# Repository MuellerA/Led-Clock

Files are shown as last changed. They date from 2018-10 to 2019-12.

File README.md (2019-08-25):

<h1>LED Clock</h1>

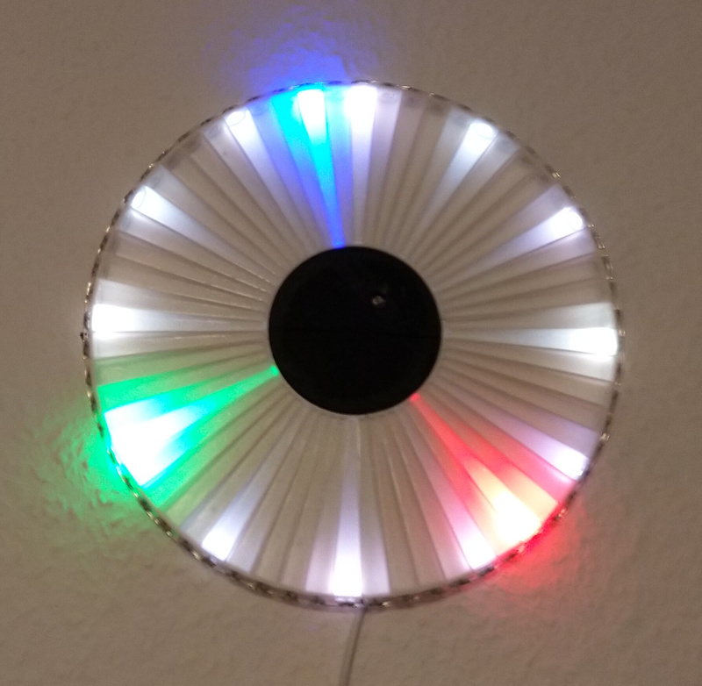
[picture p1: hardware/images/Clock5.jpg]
Clock


<p>Clock with WS2812 LEDs, controlled by a NodeMCU ESP8266 module.</p>
<p><span style="color: red">DO NOT EXPOSE THE CLOCK TO THE INTERNET<br/>The clock stores your WiFi credentials and supports remote updates</span></p>

<h2>Features</h2>
<ul>
  <li>Setting color for hour, minute, second</li>
  <li>Brighness control</li>
  <li>Use NTP for time synchronization</li>
  <li>Convert from UTC to local time and DST</li>
  <li>Manual and automatic time triggered On/Off</li>
  <li>OTA Update</li>
  <li>Optional secure HTTPS communication</li>
</ul>

<h2>Used Libraries</h2>
<ul>
  <li>Arduino 1.8.0</li>
  <li><a href="https://github.com/esp8266/Arduino">Arduino Core for ESP8266</a> (Version 2.4.2 - I had OTA Update problems with 2.5.0)</li>
  <li><a href="https://github.com/adafruit/Adafruit_NeoPixel">Adafruit NeoPixel Library</a> (Version 1.2.1)</li>
</ul>

<h2>Material</h2>
<ul>
  <li>NodeMCU v2</li>
  <li>Buck converter 12V to 5V</li>
  <li>60x WS2812 LEDs on PCB</li>
  <li>Photo resistor 5539</li>
  <li>3D printed housing</li>
  <li>Acryl glass front plate</li>
</ul>

<h2>Setup</h2>
<ol>
  <li>Open the Arduino IDE</li>
  <li>Install the required libraries</li>
  <li>Check the <a href="source/ArduinoSettings.png">Board Settings</a></li>
  <li>Load the Clock.ino sketch</li>
  <li>Modify the Password in password.h (it is used as PSK in Access Point mode and OTA Update password)</li>
  <li>Flash the ESP8266 using Arduino IDE</li>
  <li>
    Connect the NodeMCU with the buck converter, WS2812 LEDs and the photo resistor:<br/>
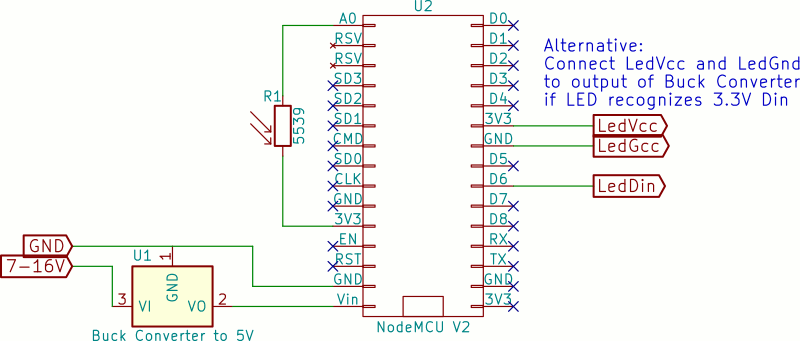
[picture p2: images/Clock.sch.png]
schematic
    <br/>
  </li>
</ol>

<h2>First Start</h2>
<ul>
  <li>Open the Serial Monitor in Arduino IDE</li>
  <li>Power on / reset the Clock</li>
  <li>Connect to Network with the SSID "Clock-xxxxxx" and the password specified in the password.h file (both are shown in the Serial Monitor)</li>
  <li>Open the web page "http://192.168.4.1"</li>
  <li>On the Settings page enter the credentials (SSID and PSK) of your Wireless LAN and press "save"</li>
  <li>The clock will now connect to your network, fetch the current time and display it</li>
  <li>Check your router for the network address of the Clock and open the page in the browser to check the other settings</li>
  <li>At next power on the clock will remember the settings</li>
</ul>

<h2>Usage</h2>
<ul>
  <li>The LEDs can be switched on/off manually and automatically. If automatic mode is enabled and the LEDs are switched manually, the automatic mode stays enabled and will switch at the next configured time again.</li>
  <li>The OTA Update username is the Name specified on the Settings page and the password is the one specified in password.h file</li>
</ul>

<h2>Security</h2>
<p>By default the Clock does not use https for communication, it's too slow. Https can be enabled in Clock.ino (#define HTTPS ...).</p>
<p>The repository contains a certificate and private key, but you should use your own. To create and upload them:</p>
<ol>
  <li>Run the script "source/make-cert.sh" to create the certificate file "cert.der" and the private key file "key.der". The script requires <a href="https://www.openssl.org/">OpenSSL</a> to be installed.</li>
  <li>Create the directory "source/Clock/data" and copy the generated files into that directory.</li>
  <li>Install the SPIFS tool for Arduino as described in the <a href="https://arduino-esp8266.readthedocs.io/en/latest/filesystem.html#uploading-files-to-file-system">ESP8266 documentation</a>.</li>
  <li>Use the Upload Tool to upload the files to the ESP8266.</li> 
</ol>

<h2>3D Print</h2>

<p>The OpenSCAD file to 3D Print the housing is in the hardware folder. STL files are available at <a href="https://www.thingiverse.com/thing:3130435">Thingiverse</a><br/>
An alternative to 3D Printing is to use a WS2812 LED ring with 60 LEDs</p>

<p>
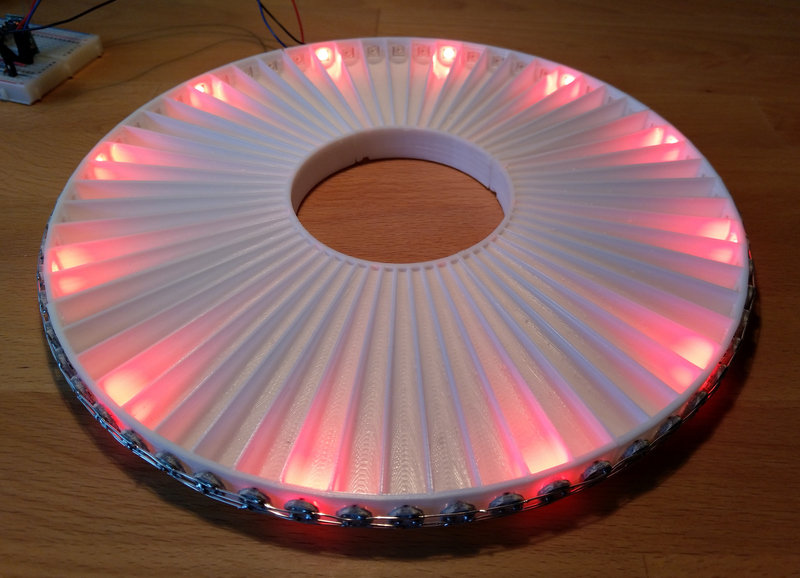
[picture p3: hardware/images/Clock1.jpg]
clock 1

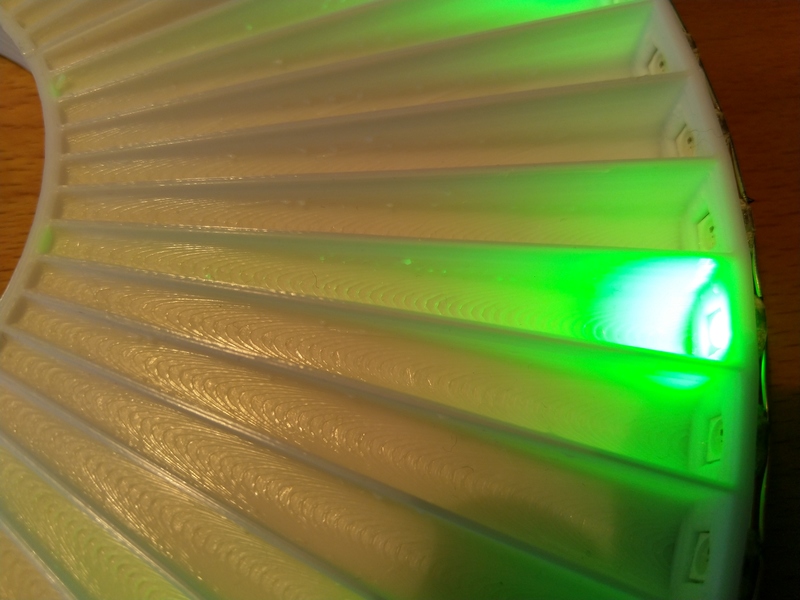
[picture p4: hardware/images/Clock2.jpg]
clock 1

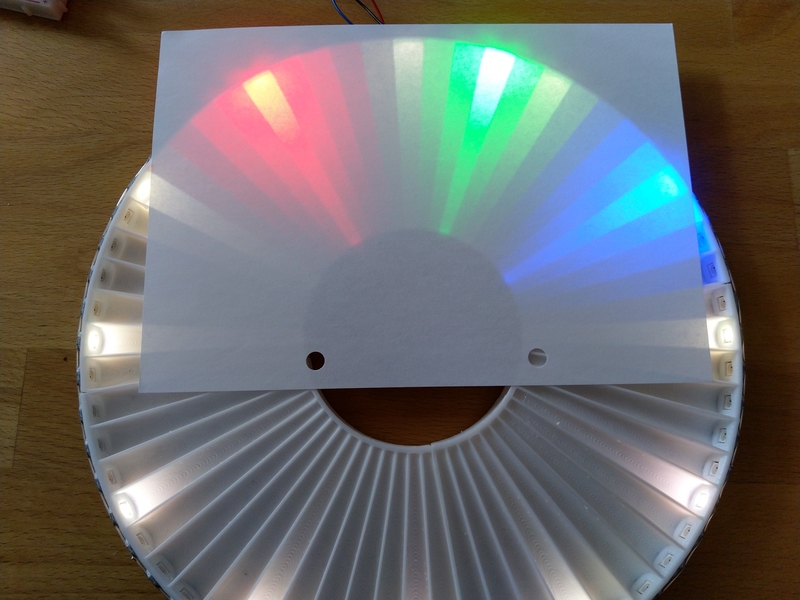
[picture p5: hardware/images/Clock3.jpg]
clock 1

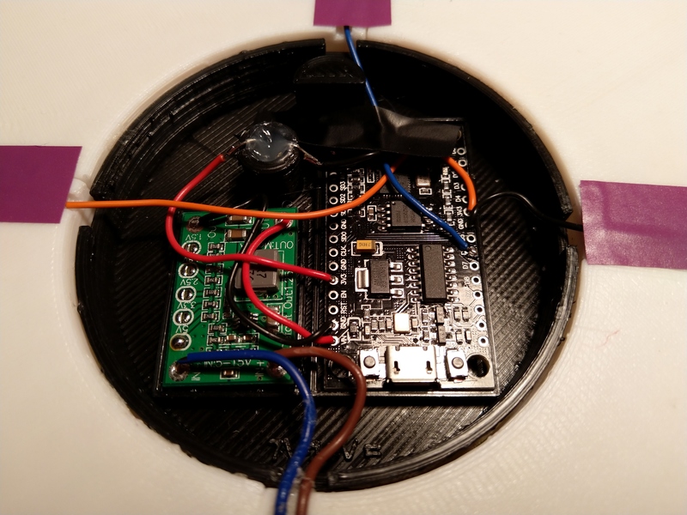
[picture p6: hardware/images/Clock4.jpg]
clock 1

</p>

<h2>UI Screenshots</h2>
<p>
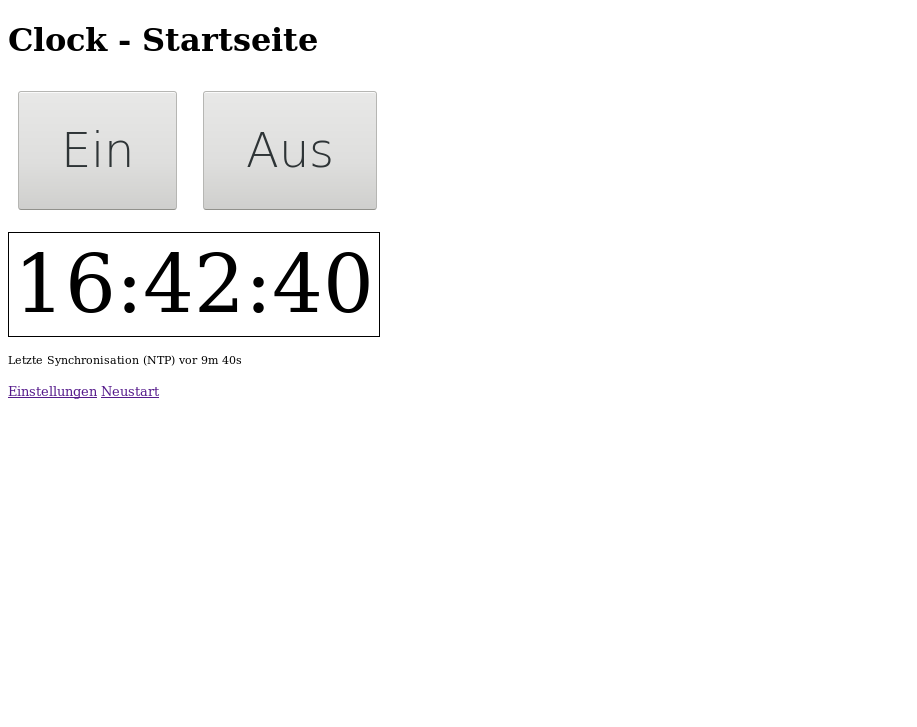
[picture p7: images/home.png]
home

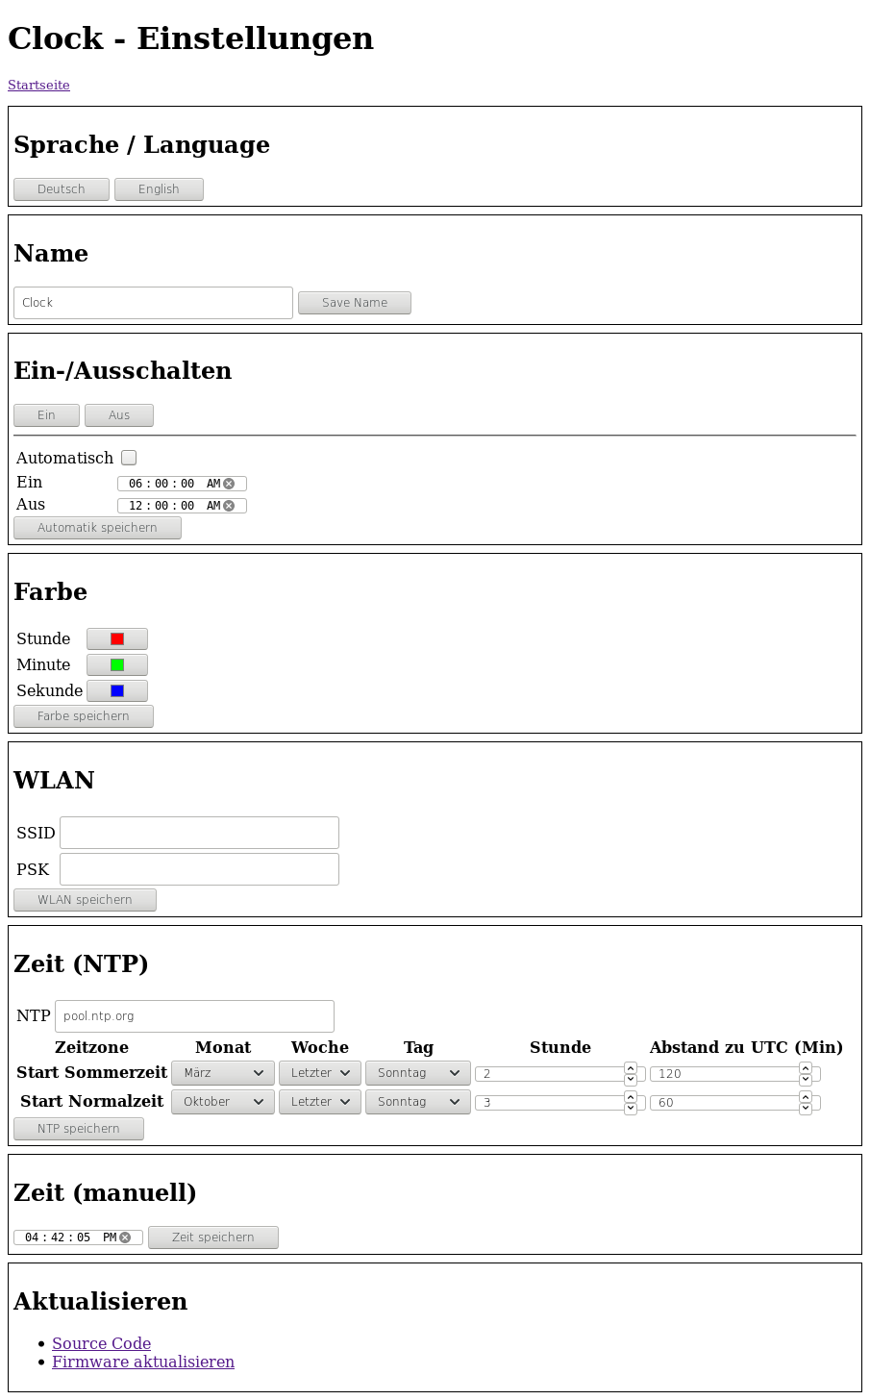
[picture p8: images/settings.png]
settings

<a style="vertical-align: top" href="images/update.png"  >update</a>
</p>

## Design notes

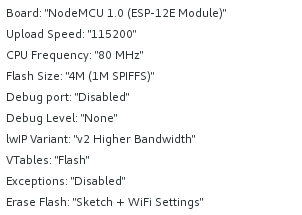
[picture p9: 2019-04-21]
source/ArduinoSettings.png

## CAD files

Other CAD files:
hardware/Clock.scad

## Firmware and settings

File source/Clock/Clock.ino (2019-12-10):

////////////////////////////////////////////////////////////////////////////////
// Clock.ino
////////////////////////////////////////////////////////////////////////////////

// HTTPS axTLS or BearSSL or none (= unsecured http)
#define HTTPS_None    0
#define HTTPS_axTLS   1
#define HTTPS_BearSSL 2
#define HTTPS HTTPS_None

#include <ESP8266WiFi.h>
#if (HTTPS == HTTPS_axTLS)
#  include <WiFiClientSecure.h>
#  include <ESP8266WebServerSecureAxTLS.h>
#elif (HTTPS == HTTPS_BearSSL)
#  include <WiFiClientSecure.h>
#  include <ESP8266WebServerSecureBearSSL.h>
#elif (HTTPS == HTTPS_None)
#include <ESP8266WebServer.h>
#else
#error "unknown macro HTTPS "
#endif
#include <ESP8266HTTPUpdateServer.h>
#include <WiFiUdp.h>
#include <FS.h>

#include <Adafruit_NeoPixel.h>

#include <map>
#include <functional>

#include "timezone.h"
#include "password.h"
#include "Clock.h"

////////////////////////////////////////////////////////////////////////////////

char HostName[16] ;

const int WS2812_NUM = 60 ;
const int WS2812_PIN = 12 ;

Adafruit_NeoPixel ws2812 = Adafruit_NeoPixel(WS2812_NUM, WS2812_PIN, NEO_GRB + NEO_KHZ800);

#if HTTPS == HTTPS_axTLS
axTLS::ESP8266WebServerSecure httpServer ( 443 ) ;
#elif HTTPS == HTTPS_BearSSL
BearSSL::ESP8266WebServerSecure httpServer ( 443 ) ;
#else
ESP8266WebServer httpServer ( 80 ) ;
#endif
ESP8266HTTPUpdateServer httpUpdater;

const uint16_t UDP_PORT = 1123 ;
WiFiUDP udp ;
Ntp ntp ;

Settings settings ;
Brightness brightness{0} ;

bool WifiConnected = false ;

TZ::TimeZone tz ;

bool Shutdown = false ;

////////////////////////////////////////////////////////////////////////////////
// util

bool ascDecToBin(char c, uint8_t &d)
{
  if (('0' <= c) && (c <= '9')) { d = c - '0'      ; return true ; }
  return false ;
}

bool ascHexToBin(char c, uint8_t &h) 
{
  if (('0' <= c) && (c <= '9')) { h = c - '0'      ; return true ; }
  if (('a' <= c) && (c <= 'f')) { h = c - 'a' + 10 ; return true ; }
  if (('A' <= c) && (c <= 'F')) { h = c - 'A' + 10 ; return true ; }
  return false ;
}

template<typename T>
bool ascIntToBin(String str, T &val)
{
  if (str.length() > 5)
    return false ;

  uint8_t e = str.length() ;
  if (e < 1)
    return false ;

  uint8_t idx = 0 ;
  bool neg = false ;

  if      (str[0] == '-') { neg = true ; idx = 1 ; }
  else if (str[0] == '+') {              idx = 1 ; }

  if (e < (idx + 1))
    return false ;
  
  T v = 0 ;
  for ( ; idx < e ; ++idx)
  {
    uint8_t d ;
    if (!ascDecToBin(str[idx], d))
      return false ;
    v = v*10 + d ;
  }
  val = neg ? -v : v ;

  return true ;
}

template<typename T>
bool ascIntToBin(String str, T &val, T min, T max)
{
  T val0 ;
  if (ascIntToBin(str, val0) &&
      (min <= val0) && (val0 <= max))
  {
    val = val0 ;
    return true ;
  }
  return false ;
}

String timeToString(uint32_t t)
{
  char buff[16] ;
  sprintf(buff, "%02ld:%02ld:%02ld", (long)(t / 60 / 60 % 24), (long)(t / 60 % 60), (long)(t % 60)) ;
  return String(buff) ;
}

uint32_t stringToTime(const String &str)
{
  long h,m,s ;
  sscanf(str.c_str(), "%02ld:%02ld:%02ld", &h, &m, &s) ;
  return uint32_t(h*60*60 + m*60 + s) ;
}

////////////////////////////////////////////////////////////////////////////////

Brightness::Brightness(unsigned int pin) : _pin(pin), _min{0.1}
{
}

void Brightness::init()
{
  unsigned long v = analogRead(_pin) ;
  
  for (unsigned int i = 0 ; i < _size ; ++i)
    _val[i] = v ;
  _sum = v * _size ;
  _idx = 0 ;
}

void Brightness::update()
{
  unsigned long v = analogRead(_pin) ;
  _sum -= _val[_idx] ;
  _val[_idx] = v ;
  _sum += _val[_idx] ;
  _idx = (_idx+1) % _size ;
}

double Brightness::operator()() const
{
  double v = (double)(_sum) / ((double)(_size*1024)) ;
  return (v < _min) ? _min : v ;    
}

////////////////////////////////////////////////////////////////////////////////

void updateClock(uint64_t localTime)
{
  if (settings._autoOnOffEnable)
  {
    uint32_t lt = localTime % (24*60*60) ;
    if (lt == settings._autoOnOffOff) settings._state = State::Off ;
    if (lt == settings._autoOnOffOn ) settings._state = State::On  ;
  }
  
  switch (settings._state)
  {
  case State::On:
  default:
    {
      static Color c15(0x18, 0x18, 0x18) ;
      static Color c05(0x08, 0x08, 0x08) ;
      static Color c01(0x00, 0x00, 0x00) ;
      static Color c15w(0x20, 0x00, 0x00) ;
      static Color c05w(0x0b, 0x00, 0x00) ;
  
      uint8_t second = localTime % 60 ;
      uint8_t minute = localTime / 60 % 60 ;
      uint8_t hour   = localTime / 60 / 60 % 12 ;

      double b = brightness() ;

      Color c15b = ntp.isSync() ? c15.brightness(b) : c15w.brightness(b) ;
      Color c05b = ntp.isSync() ? c05.brightness(b) : c05w.brightness(b) ;
      Color c01b = c01.brightness(b) ;
      Color hb   = settings._colHour  .brightness(b) ;
      Color mb   = settings._colMinute.brightness(b) ;
      Color sb   = settings._colSecond.brightness(b) ;
  
      for (unsigned char i = 0 ; i < 60 ; ++i)
      {
        Color c ;

        if (i == (hour*5 + (minute+6)/12) % 60) c = hb ;
        if (i == minute)                        c.mix(mb) ;
        if (i == second)                        c.mix(sb) ;

        if (!c)
        {
          if      ((i % 15) == 0) c = c15b ;
          else if ((i %  5) == 0) c = c05b ;
          else                    c = c01b ;
        }

        ws2812.setPixelColor(i, c.rgb()) ;
      }
    }
    break ;
  case State::Off:
    {
      ws2812.clear() ;
    }
  }
  ws2812.show() ;
}

void updateClock()
{
  static uint8_t cnt ;
  static uint8_t idx ;
    
  uint32_t rgb ;
  switch (cnt)
  {
  case 0: rgb = settings._colHour  .rgb() ; break ;
  case 1: rgb = settings._colMinute.rgb() ; break ;
  case 2: rgb = settings._colSecond.rgb() ; break ;
  }

  for (uint8_t i = 0 ; i < 60 ; ++i)
  {
    ws2812.setPixelColor(i, ((i % 5) == idx) ? rgb : 0) ;
  }
  cnt = (cnt + 1) % 3 ;
  idx = (idx + 1) % 5 ;

  ws2812.show() ;
}

////////////////////////////////////////////////////////////////////////////////
// Arduino Main
////////////////////////////////////////////////////////////////////////////////

void setup()
{
  sprintf(HostName, "clock-%06x", ESP.getChipId()) ;
  
  Serial.begin ( 115200 );
  Serial.printf("\n") ;
  //Serial.setDebugOutput(true) ;
  
  SPIFFS.begin() ;
  
  settings.load() ;
  Serial.printf("AP: SSID=%s / PSK=%s / Channel=%d\n", settings._apSsid.c_str(), settings._apPsk.c_str(), settings._apChan) ;
  
  WifiSetup() ;
  HttpSetup() ;
  
  udp.begin(UDP_PORT) ;

  ws2812.begin() ;

  brightness.init() ;
}

////////////////////////////////////////////////////////////////////////////////

void loop()
{
  uint32_t now = millis() ;
  
  if (Shutdown)
  {
    static uint8_t  cnt  = 0 ;
    static uint32_t last = 0 ;

    if (now - last > 25)
    {
      for (uint8_t i = 0 ; i < 60 ; ++i)
      {
        if ((i <= 0 + cnt) || (i >= 60 - cnt))
          ws2812.setPixelColor(i, 0x0f0000) ;
        else
          ws2812.setPixelColor(i, 0x000000) ;
      }
      ws2812.show() ;
      cnt = cnt + 1 ;
      last = now ;

      if (cnt > 30)
        ESP.restart() ;
    }
    
    return ;
  }
  
  int udpLen = udp.parsePacket() ;
  if (udpLen)
  {
    if ((udp.remotePort() == Ntp::port()) &&
        (udpLen == Ntp::size()))
      ntp.rx(udp) ;
  }
  
  WifiLoop() ;

  // Clock
  {
    if (ntp.valid())
    {
      if (ntp.inc())
      {
        uint64_t local = ntp.local() ;
        updateClock(local) ;
      }
    }
    else
    {
      static uint32_t last = 0 ;
      if (now - last > 1000)
      {
        updateClock() ;
        last = now ;
      }
    }
  }

  {
    static uint32_t last = 0 ;
    if (now - last > 333)
    {
      brightness.update() ;
      last = now ;                                                                               
    }
  }
  
  // NTP
  if (WifiConnected)
    ntp.tx(udp, settings._ntp) ;
  
  httpServer.handleClient() ;

  delay(50) ;
}

////////////////////////////////////////////////////////////////////////////////
// EOF
////////////////////////////////////////////////////////////////////////////////

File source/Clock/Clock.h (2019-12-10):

////////////////////////////////////////////////////////////////////////////////
// Clock.h
////////////////////////////////////////////////////////////////////////////////

extern char HostName[] ;

////////////////////////////////////////////////////////////////////////////////

class HttpBuff ;

////////////////////////////////////////////////////////////////////////////////

struct Brightness
{
  static const size_t _size = 16 ;
  Brightness(unsigned int pin) ;
  
  void init() ;
  void update() ;
  double operator()() const ; // value between Min and 1.0

  const double _min ;
  unsigned long _pin ;
  unsigned long _val[_size] ;
  unsigned long _sum ;
  unsigned long _idx ;
} ;

////////////////////////////////////////////////////////////////////////////////

class Color
{
public:
  Color() ;
  Color(uint8_t r, uint8_t g, uint8_t b) ;
  
  void set(uint8_t r, uint8_t g, uint8_t b) ;
  uint32_t rgb() const ;
  void mix(const Color &c) ;
  bool operator!() const ;
  Color brightness(double b) const ;
  String toString() const ;
  bool fromString(const String &str) ;

private:
  bool fromString1(const String &s, uint8_t offset, uint8_t &v) const ;
  
  uint8_t _r ;
  uint8_t _g ;
  uint8_t _b ;
} ;

////////////////////////////////////////////////////////////////////////////////

enum class Lang
{
  EN,
  DE,
  Size // last
} ;

enum class State
{
  Off,
  On,
} ;

struct Settings
{
  Settings() = default ;
  Settings(const Settings &) = delete ;
  Settings& operator=(const Settings &) = delete ;

  void load() ;
  void save() const ;

  // Language
  Lang _lang { Lang::DE } ;

  // State
  State _state { State::On } ;
  bool     _autoOnOffEnable = false ;
  uint32_t _autoOnOffOn     = 6 * 60*60 ;
  uint32_t _autoOnOffOff    = 0 * 60*60 ;
  
  // Wifi Access Point
  String  _apSsid ;
  String  _apPsk  ;
  uint8_t _apChan ;

  // Wifi Station
  String _ssid ;
  String _psk ;

  // NTP
  String    _ntp { "pool.ntp.org" } ;
  TZ::Month _tzDstMonth  { TZ::Month:: Mar } ;
  TZ::Week  _tzDstWeek   { TZ::Week:: Last } ;
  TZ::Day   _tzDstDay    { TZ::Day::   Sun } ;
  uint8_t   _tzDstHour   {               2 } ;
  int16_t   _tzDstOffset {             120 } ;
  TZ::Month _tzStdMonth  { TZ::Month:: Oct } ;
  TZ::Week  _tzStdWeek   { TZ::Week:: Last } ;
  TZ::Day   _tzStdDay    { TZ::Day::   Sun } ;
  uint8_t   _tzStdHour   {               3 } ;
  int16_t   _tzStdOffset {              60 } ;

  // Color  
  Color _colHour   { 0xff, 0x00, 0x00 } ; // rgb
  Color _colMinute { 0x00, 0xff, 0x00 } ; // rgb
  Color _colSecond { 0x00, 0x00, 0xff } ; // rgb
} ;

////////////////////////////////////////////////////////////////////////////////

class Ntp
{
#pragma pack(push, 1)
  struct NtpData
  {
    uint8_t liVnMode ;        // 0 [2:3:3]
    uint8_t stratum ;
    uint8_t poll ;
    uint8_t precision ;
    uint32_t rootDelay ;      // 4 
    uint32_t rootDispersion ;
    uint32_t referenceId ;
    uint32_t referenceTsSec ; // 16
    uint32_t referenceTsFrac ;
    uint32_t originTsSec ;    // 24
    uint32_t originTsFrac ;
    uint32_t receiveTsSec ;   // 32
    uint32_t receiveTsFrac ;
    uint32_t transmitTsSec ;  // 40
    uint32_t transmitTsFrac ;
  } ;
#pragma pop

  enum class State
  {
    off     = 0,
    wait    = 1,
    success = 2,
    force   = 3,
  } ;

public:
  void     start() ; // enable transmitting ntp messages
  void     stop() ;  // disable transmitting ntp messages
  
  bool     valid()  const { return _valid ; } // a time was set (manually or by NTP)
  bool     isNtp()  const { return _isNtp ; } // time was received via NTP
  bool     inc() ; // time changed
  uint64_t local() const ; // current local time
  void     setLocal(uint64_t local) ;
  
  void printSerial(const NtpData &data) const ;

  String toLocalString() const ;
  bool   fromLocalString(const String &str) ;
  bool   isSync() const ; // last succesful sync is not too long ago
  String lastSyncToString() const ;
  
  static uint16_t port() { return 123 ; }
  static uint16_t size() { return sizeof(NtpData) ; }
  bool tx(WiFiUDP &udp, const String &ntpServer) ;
  bool rx(WiFiUDP &udp) ;

private:
  bool fromLocalString1(const String &s, uint8_t offset, uint8_t &v) const ;

private:
  static const int _delayWait    =      15 * 1000 ; // 15 sec
  static const int _delaySuccess = 30 * 60 * 1000 ; // 30 min
  
  static const int _delayWarnSyncNtp    =       6 * 60 * 60 ; // 3 hour
  static const int _delayWarnSyncManual =  7 * 24 * 60 * 60 ; // 1 week
  
  NtpData _txData ;
  NtpData _rxData ;

  State    _state       = State::off ;
  bool     _valid       = false ;
  bool     _next59      = false ;
  bool     _next61      = false ;
  uint32_t _lastInc     = 0 ;     // last millis when inc'ed current time
  uint32_t _lastRequest = 0 ;     // millis of last request
  uint64_t _tsReceived  = 0 ;     // last received ntp time
  uint64_t _tsTransmit  = 0 ;     // last tx timestamp
  bool     _isNtp       = false ; // NTP vs manual setting (== utc time vs local time)
  uint64_t _current     = 0 ;     // current utc or local time
  uint64_t _lastSync    = 0 ;     // last sync (ntp or manual)
  
} ;

////////////////////////////////////////////////////////////////////////////////
// EOF
////////////////////////////////////////////////////////////////////////////////

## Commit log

2018-10-01 fix spacer_width calculation ; add License
    [Clock.scad]
2018-10-24 update screenshots ; add missing files
    [Http.ino]
2018-10-28 fix dst to std time change
    [Clock.h, Http.ino]
2018-11-11 add on/off to ui
    [Clock.scad]
2018-11-17 udpate Thingiverse files
    [Clock.scad]
2019-04-21 On/Off button on Startpage Disable HTTPS per default
2019-08-25 hour arm
